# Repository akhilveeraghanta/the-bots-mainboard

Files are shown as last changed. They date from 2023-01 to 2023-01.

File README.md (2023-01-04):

# The Bots Mainboard

This is my first PCB design project. The majoriy of this board/schematics were created watching [Phils Lab](https://www.youtube.com/@PhilsLab) on youtube and using his projects as examples. 

The soccer playing AI will compute target velocities for all 6 robots and send them over USB to the mainboard, which will then send the velocity data over radio. Each robot will have its own mainboard, receive the pacet over radio, unpack and send a velocity command over the CAN Bus (which is then picked up by the motor controllers)

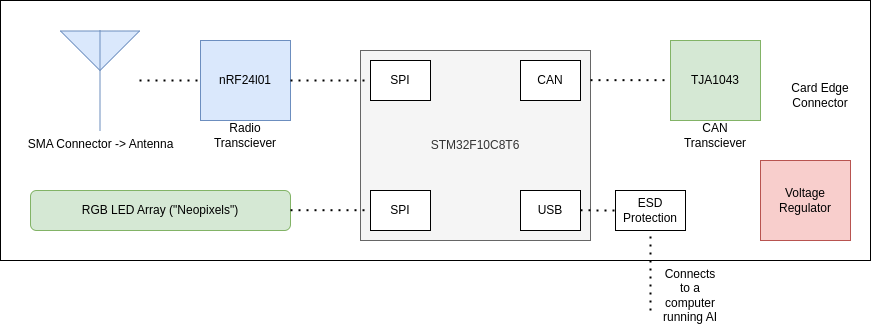
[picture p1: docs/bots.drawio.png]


So the main goal of the board is to act as a radio to CAN bridge if flashed as a robot, and a radio to USB bridge if flashed as a dongle and plugged into the computer running AI.

BoardyMcBoardFace

Additionally, the ball detector circuit, when plugged into a robot will be facing the "mouth" of the robot to detect any balls that enter. This helps with determining when to kick/chip the golf ball.

Here is one of our competitors, UBC Thunderbots's robot to put this board into perspective. (We don't have robots yet)



and more info about robocup can be [found here](https://ssl.robocup.org/)

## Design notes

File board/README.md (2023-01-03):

# the-bots-mainboard
The main board for the the bots SSL robocup team

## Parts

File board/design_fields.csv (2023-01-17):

Refs | Datasheet | Footprint | Value
C1 | ~ | Capacitor_SMD:C_0402_1005Metric | 10u
C10 | ~ | Capacitor_SMD:C_0402_1005Metric | 10n
C11 | ~ | Capacitor_SMD:C_0402_1005Metric | 10n
C12 | ~ | Capacitor_SMD:C_0402_1005Metric | 10n
C13 | ~ | Capacitor_SMD:C_0402_1005Metric | 0.1u
C14 | ~ | Capacitor_SMD:C_0402_1005Metric | 12p
C15 | ~ | Capacitor_SMD:C_0402_1005Metric | 12p
C16 | ~ | Capacitor_SMD:C_0402_1005Metric | 33n
C17 | ~ | Capacitor_SMD:C_0402_1005Metric | 10p
C18 | ~ | Capacitor_SMD:C_0402_1005Metric | 10p
C19 | ~ | Capacitor_SMD:C_0402_1005Metric | 1p5
C2 | ~ | Capacitor_SMD:C_0402_1005Metric | 100n
C20 | ~ | Capacitor_SMD:C_0402_1005Metric | 100n
C21 | ~ | Capacitor_SMD:C_0402_1005Metric | 1p
C22 | ~ | Capacitor_SMD:C_0402_1005Metric | 2n2
C23 | ~ | Capacitor_SMD:C_0402_1005Metric | 4p7
C25 | ~ | Capacitor_SMD:C_0402_1005Metric | 10n
C26 | ~ | Capacitor_SMD:C_0402_1005Metric | 22u
C27 | ~ | Capacitor_SMD:C_0805_2012Metric | 22u
C29 | ~ | Capacitor_SMD:C_0402_1005Metric | 10n
C3 | ~ | Capacitor_SMD:C_0402_1005Metric | 100n
C30 | ~ | Capacitor_SMD:C_0402_1005Metric | 0.1u
C32 | ~ | Capacitor_SMD:C_0402_1005Metric | 100n
C33 | ~ | Capacitor_SMD:C_0402_1005Metric | 100n
C34 | ~ | Capacitor_SMD:C_0402_1005Metric | 100n
C35 | ~ | Capacitor_SMD:C_0402_1005Metric | 100n
C36 | ~ | Capacitor_SMD:C_0402_1005Metric | 100n
C37 | ~ | Capacitor_SMD:C_0402_1005Metric | 100n
C38 | ~ | Capacitor_SMD:C_0402_1005Metric | 100n
C39 | ~ | Capacitor_SMD:C_0402_1005Metric | 100n
C4 | ~ | Capacitor_SMD:C_0402_1005Metric | 100n
C40 | ~ | Capacitor_SMD:C_0402_1005Metric | 100n
C41 | ~ | Capacitor_SMD:C_0402_1005Metric | 100n
C42 | ~ | Capacitor_SMD:C_0402_1005Metric | 100n
C43 | ~ | Capacitor_SMD:C_0402_1005Metric | 100n
C44 | ~ | Capacitor_SMD:C_0402_1005Metric | 100n
C45 | ~ | Capacitor_SMD:C_0402_1005Metric | 100n
C46 | ~ | Capacitor_SMD:C_0402_1005Metric | 100n
C5 | ~ | Capacitor_SMD:C_0402_1005Metric | 100n
C6 | ~ | Capacitor_SMD:C_0402_1005Metric | 100n
C7 | ~ | Capacitor_SMD:C_0402_1005Metric | 1u
C8 | ~ | Capacitor_SMD:C_0402_1005Metric | 1u
C9 | ~ | Capacitor_SMD:C_0402_1005Metric | 10u
D1 | https://cdn-shop.adafruit.com/datasheets/WS2812B.pdf | LED_SMD:LED_WS2812B-2020_PLCC4_2.0x2.0mm | WS2812B
D10 | ~ | LED_THT:LED_D5.0mm_IRGrey | D_Photo
D11 | https://cdn-shop.adafruit.com/datasheets/WS2812B.pdf | LED_SMD:LED_WS2812B-2020_PLCC4_2.0x2.0mm | WS2812B
D12 | https://cdn-shop.adafruit.com/datasheets/WS2812B.pdf | LED_SMD:LED_WS2812B-2020_PLCC4_2.0x2.0mm | WS2812B
D13 | https://cdn-shop.adafruit.com/datasheets/WS2812B.pdf | LED_SMD:LED_WS2812B-2020_PLCC4_2.0x2.0mm | WS2812B
D14 | https://cdn-shop.adafruit.com/datasheets/WS2812B.pdf | LED_SMD:LED_WS2812B-2020_PLCC4_2.0x2.0mm | WS2812B
D15 | https://cdn-shop.adafruit.com/datasheets/WS2812B.pdf | LED_SMD:LED_WS2812B-2020_PLCC4_2.0x2.0mm | WS2812B
D16 | https://cdn-shop.adafruit.com/datasheets/WS2812B.pdf | LED_SMD:LED_WS2812B-2020_PLCC4_2.0x2.0mm | WS2812B
D17 | https://cdn-shop.adafruit.com/datasheets/WS2812B.pdf | LED_SMD:LED_WS2812B-2020_PLCC4_2.0x2.0mm | WS2812B
D18 | https://cdn-shop.adafruit.com/datasheets/WS2812B.pdf | LED_SMD:LED_WS2812B-2020_PLCC4_2.0x2.0mm | WS2812B
D19 | https://cdn-shop.adafruit.com/datasheets/WS2812B.pdf | LED_SMD:LED_WS2812B-2020_PLCC4_2.0x2.0mm | WS2812B
D2 | ~ | LED_SMD:LED_0402_1005Metric | LED
D20 | https://cdn-shop.adafruit.com/datasheets/WS2812B.pdf | LED_SMD:LED_WS2812B-2020_PLCC4_2.0x2.0mm | WS2812B
D21 | https://cdn-shop.adafruit.com/datasheets/WS2812B.pdf | LED_SMD:LED_WS2812B-2020_PLCC4_2.0x2.0mm | WS2812B
D22 | ~ | LED_SMD:LED_0402_1005Metric | LED
D23 | https://cdn-shop.adafruit.com/datasheets/WS2812B.pdf | LED_SMD:LED_WS2812B-2020_PLCC4_2.0x2.0mm | WS2812B
D24 | https://cdn-shop.adafruit.com/datasheets/WS2812B.pdf | LED_SMD:LED_WS2812B-2020_PLCC4_2.0x2.0mm | WS2812B
D25 | https://cdn-shop.adafruit.com/datasheets/WS2812B.pdf | LED_SMD:LED_WS2812B-2020_PLCC4_2.0x2.0mm | WS2812B
D26 | https://cdn-shop.adafruit.com/datasheets/WS2812B.pdf | LED_SMD:LED_WS2812B-2020_PLCC4_2.0x2.0mm | WS2812B
D27 | ~ | LED_SMD:LED_0402_1005Metric | LED
D28 | ~ | LED_SMD:LED_0402_1005Metric | LED
D3 | http://www.alliedelec.com/m/d/40788c34903a719969df15f1fbea1056.pdf | LED_THT:LED_D5.0mm_IRGrey | LD271
D4 | ~ | LED_THT:LED_D5.0mm_IRGrey | D_Photo
D5 | ~ | Diode_SMD:D_0805_2012Metric | D_Schottky
D6 | ~ | Diode_SMD:D_0805_2012Metric | D_Schottky
D7 | https://cdn-shop.adafruit.com/datasheets/WS2812B.pdf | LED_SMD:LED_WS2812B-2020_PLCC4_2.0x2.0mm | WS2812B
D8 | ~ | LED_SMD:LED_0402_1005Metric | LED
D9 | http://www.alliedelec.com/m/d/40788c34903a719969df15f1fbea1056.pdf | LED_THT:LED_D5.0mm_IRGrey | LD271
FB1 | ~ | Inductor_SMD:L_0402_1005Metric | 120R
J1 | ~ | Connector_Coaxial:SMA_Samtec_SMA-J-P-X-ST-EM1_EdgeMount | SMA
J2 | ~ | Connector_PinHeader_1.27mm:PinHeader_2x05_P1.27mm_Vertical | ARM 10pin
J3 | ~ | Connector_USB:USB_Micro-B_Molex_47346-0001 | USB_B_Micro
J4 | ~ | Connector_PinHeader_1.27mm:PinHeader_1x02_P1.27mm_Vertical | Conn_01x02_Male
J5 | ~ | Connector_PinHeader_1.27mm:PinHeader_1x02_P1.27mm_Vertical | Conn_01x02_Male
J6 | ~ | Connector_PinHeader_1.27mm:PinHeader_1x02_P1.27mm_Vertical | Conn_01x02_Male
JP1 | ~ | Connector_PinHeader_1.27mm:PinHeader_1x02_P1.27mm_Vertical | Jumper_2_Open
JP2 | ~ | Connector_PinHeader_1.27mm:PinHeader_1x03_P1.27mm_Vertical | Jumper_3_Open
L1 | ~ | Inductor_SMD:L_0402_1005Metric | 3n9
L2 | ~ | Inductor_SMD:L_0402_1005Metric | 8n2
L3 | ~ | Inductor_SMD:L_0402_1005Metric | 2n7
R1 | ~ | Resistor_SMD:R_0402_1005Metric | 1M
R10 | ~ | Resistor_SMD:R_0402_1005Metric | 10k
R11 | ~ | Resistor_SMD:R_0402_1005Metric | 10k
R12 | ~ | Resistor_SMD:R_0402_1005Metric | 1k
R13 | ~ | Resistor_SMD:R_0402_1005Metric | 1k
R14 | ~ | Resistor_SMD:R_0402_1005Metric | 1k
R15 | ~ | Resistor_SMD:R_0402_1005Metric | 1k
R2 | ~ | Resistor_SMD:R_0402_1005Metric | 22k
R3 | ~ | Resistor_SMD:R_0402_1005Metric | 120
R4 | ~ | Resistor_SMD:R_0402_1005Metric | 100
R5 | ~ | Resistor_SMD:R_0402_1005Metric | 10k
R6 | ~ | Resistor_SMD:R_0402_1005Metric | 10k
R7 | ~ | Resistor_SMD:R_0402_1005Metric | 1k
R8 | ~ | Resistor_SMD:R_0402_1005Metric | 1k
R9 | ~ | Resistor_SMD:R_0402_1005Metric | 100
RV1 | ~ | Potentiometer_THT:Potentiometer_Bourns_3266X_Horizontal | R_POT 10k
RV2 | ~ | Potentiometer_THT:Potentiometer_Bourns_3266X_Horizontal | R_POT 10k
SW1 | ~ | Button_Switch_SMD:SW_Push_SPST_NO_Alps_SKRK | SW_Push
U$1 |  | ExtraStuff:M.2-B-KEY | M.2-B-KEY
U1 | http://www.nordicsemi.com/eng/content/download/2726/34069/file/nRF24L01P_Product_Specification_1_0.pdf | Package_DFN_QFN:QFN-20-1EP_4x4mm_P0.5mm_EP2.5x2.5mm | nRF24L01P
U2 | http://www.st.com/st-web-ui/static/active/en/resource/technical/document/datasheet/CD00161566.pdf | Package_QFP:LQFP-48_7x7mm_P0.5mm | STM32F103CBT6
U3 | http://www2.st.com/resource/en/datasheet/CD00050750.pdf | Package_TO_SOT_SMD:SOT-23-6 | USBLC6-2SC6
U4 | http://www.ti.com/lit/ds/symlink/lm393.pdf | Package_SO:SOIC-8_3.9x4.9mm_P1.27mm | LM393
U5 | http://www.advanced-monolithic.com/pdf/ds1117.pdf | Package_TO_SOT_SMD:SOT-223-3_TabPin2 | AMS1117-5.0
U6 | http://www.advanced-monolithic.com/pdf/ds1117.pdf | Package_TO_SOT_SMD:SOT-223-3_TabPin2 | AMS1117-3.3
U7 | http://www2.st.com/resource/en/datasheet/CD00050750.pdf | Package_TO_SOT_SMD:SOT-23-6 | USBLC6-2SC6
U8 | http://www2.st.com/resource/en/datasheet/CD00050750.pdf | Package_TO_SOT_SMD:SOT-23-6 | USBLC6-2SC6
U9 | http://www.nxp.com/documents/data_sheet/TJA1051.pdf | Package_SO:SOIC-8_3.9x4.9mm_P1.27mm | TJA1051T-3
Y1 | ~ | Crystal:Crystal_SMD_3225-4Pin_3.2x2.5mm | 16MHz
Y2 | ~ | Crystal:Crystal_SMD_3225-4Pin_3.2x2.5mm | 16MHz

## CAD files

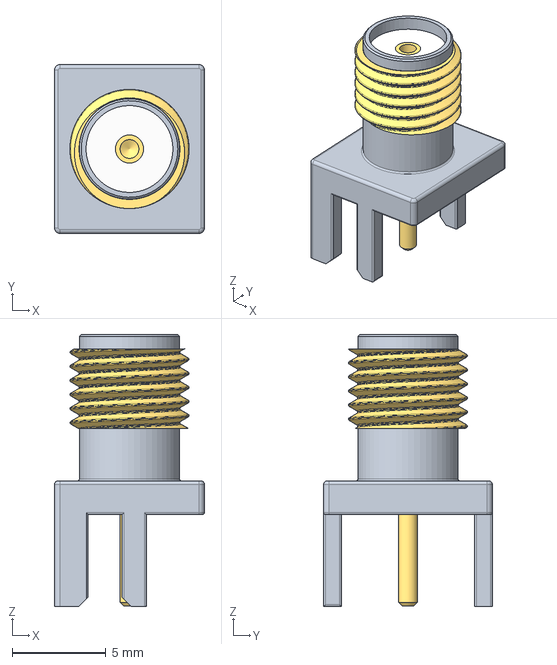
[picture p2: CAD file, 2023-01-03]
board/SMA-20.stp
8.00 x 9.00 x 14.5 mm

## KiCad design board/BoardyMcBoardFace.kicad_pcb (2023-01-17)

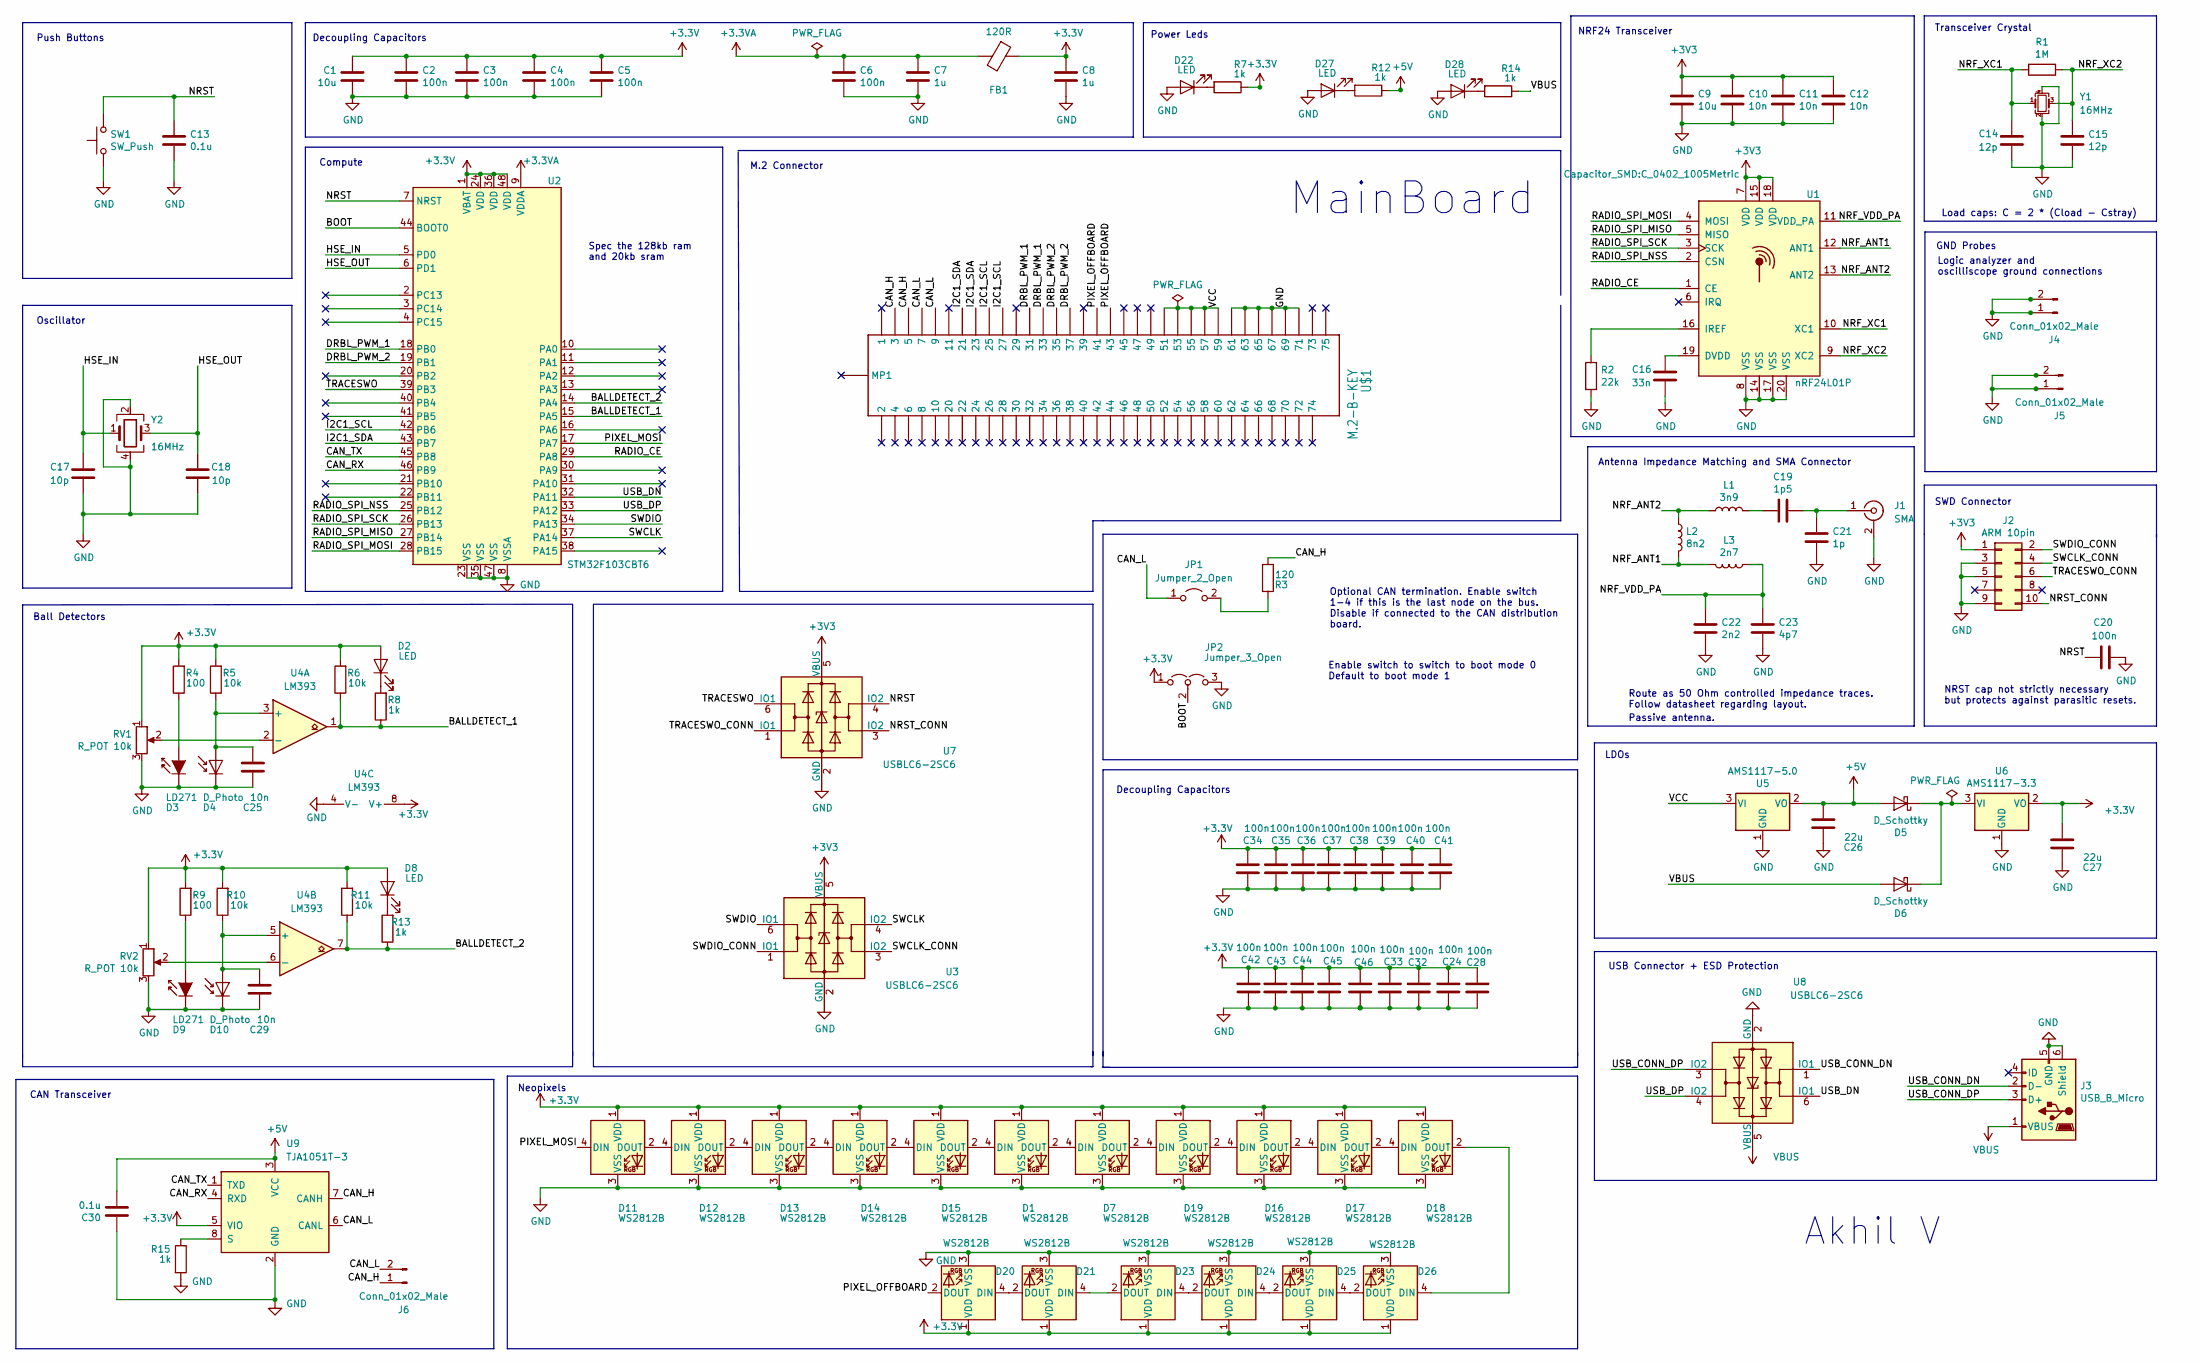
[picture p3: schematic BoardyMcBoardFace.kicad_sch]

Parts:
C1, C9: 10u; C_0402_1005Metric
C2, C3, C4, C5, C6, C20, C24, C28, C32, C33, C34, C35, C36, C37, C38, C39, C40, C41, C42, C43, C44, C45, C46: 100n; C_0402_1005Metric
C7, C8: 1u; C_0402_1005Metric
C10, C11, C12, C25, C29: 10n; C_0402_1005Metric
C13, C30: 0.1u; C_0402_1005Metric
C14, C15: 12p; C_0402_1005Metric
C16: 33n; C_0402_1005Metric
C17, C18: 10p; C_0402_1005Metric
C19: 1p5; C_0402_1005Metric
C21: 1p; C_0402_1005Metric
C22: 2n2; C_0402_1005Metric
C23: 4p7; C_0402_1005Metric
C26: 22u; C_0402_1005Metric
C27: 22u; C_0805_2012Metric
D1, D7, D11, D12, D13, D14, D15, D16, D17, D18, D19, D20, D21, D23, D24, D25, D26: WS2812B; LED_WS2812B-2020_PLCC4_2.0x2.0mm
D2, D8, D22, D27, D28: LED; LED_0402_1005Metric
D3, D9: LD271; LED_D5.0mm_IRGrey
D4, D10: D_Photo; LED_D5.0mm_IRGrey
D5, D6: D_Schottky; D_0805_2012Metric
FB1: 120R; L_0805_2012Metric
J1: SMA; SMA_Samtec_SMA-J-P-X-ST-EM1_EdgeMount
J2: ARM 10pin; PinHeader_2x05_P1.27mm_Vertical
J3: USB_B_Micro; USB_Micro-B_Molex_47346-0001
J4, J5, J6: Conn_01x02_Male; PinHeader_1x02_P1.27mm_Vertical
JP1: Jumper_2_Open; PinHeader_1x02_P1.27mm_Vertical
JP2: Jumper_3_Open; PinHeader_1x03_P1.27mm_Vertical
L1: 3n9; L_0402_1005Metric
L2: 8n2; L_0402_1005Metric
L3: 2n7; L_0402_1005Metric
R1: 1M; R_0402_1005Metric
R2: 22k; R_0402_1005Metric
R3: 120; R_0402_1005Metric
R4, R9: 100; R_0402_1005Metric
R5, R6, R10, R11: 10k; R_0402_1005Metric
R7, R8, R12, R13, R14, R15: 1k; R_0402_1005Metric
RV1, RV2: R_POT 10k; Potentiometer_Bourns_3266X_Horizontal
SW1: SW_Push; TS-1187A-B-A-B
U1: nRF24L01P; QFN-20-1EP_4x4mm_P0.5mm_EP2.5x2.5mm
U2: STM32F103CBT6; LQFP-48_7x7mm_P0.5mm
U3, U7, U8: USBLC6-2SC6; SOT-23-6
U4: LM393; SOIC-8_3.9x4.9mm_P1.27mm
U5: AMS1117-5.0; SOT-223-3_TabPin2
U6: AMS1117-3.3; SOT-223-3_TabPin2
U9: TJA1051T-3; SOIC-8_3.9x4.9mm_P1.27mm
U$1: M.2-B-KEY
Y1, Y2: 16MHz; Crystal_SMD_3225-4Pin_3.2x2.5mm

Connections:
+3.3VA: C6.1, C7.1, FB1.2, U2.9 (VDDA)
+5V: C26.2, C30.2, D5.2 (A), R12.1, U5.2 (VO), U9.3 (VCC)
/BALLDETECT_1: R6.1, R8.1, U2.15 (PA5), U4.1
/BALLDETECT_2: R11.1, R13.1, U2.14 (PA4), U4.7
/BOOT: JP2.2 (C), U2.44 (BOOT0)
/CAN_H: J6.1, R3.1, U9.7 (CANH), U$1.P$3 (3), U$1.P$5 (5)
/CAN_L: J6.2, JP1.1 (A), U9.6 (CANL), U$1.P$7 (7), U$1.P$9 (9)
/CAN_RX: U2.46 (PB9), U9.4 (RXD)
/CAN_TX: U2.45 (PB8), U9.1 (TXD)
/DRBL_PWM_1: U2.18 (PB0), U$1.P$31 (31), U$1.P$33 (33)
/DRBL_PWM_2: U2.19 (PB1), U$1.P$35 (35), U$1.P$37 (37)
/HSE_IN: C17.1, U2.5 (PD0), Y2.1
/HSE_OUT: C18.1, U2.6 (PD1), Y2.3
/I2C1_SCL: U2.42 (PB6), U$1.P$25 (25), U$1.P$27 (27)
/I2C1_SDA: U2.43 (PB7), U$1.P$21 (21), U$1.P$23 (23)
/NRF_ANT1: L2.2, L3.2, U1.12 (ANT1)
/NRF_ANT2: L1.1, L2.1, U1.13 (ANT2)
/NRF_VDD_PA: C22.2, C23.2, L3.1, U1.11 (VDD_PA)
/NRF_XC1: C14.1, R1.2, U1.10 (XC1), Y1.1
/NRF_XC2: C15.1, R1.1, U1.9 (XC2), Y1.3
/NRST: C13.1, C20.1, SW1.2, U2.7 (NRST), U7.4 (IO2)
/NRST_CONN: J2.10, U7.3 (IO2)
/PIXEL_MOSI: D11.4 (DIN), U2.17 (PA7)
/PIXEL_OFFBOARD: D20.2 (DOUT), U$1.P$41 (41), U$1.P$43 (43)
/RADIO_CE: U1.1 (CE), U2.29 (PA8)
/RADIO_SPI_MISO: U1.5 (MISO), U2.27 (PB14)
/RADIO_SPI_MOSI: U1.4 (MOSI), U2.28 (PB15)
/RADIO_SPI_NSS: U1.2 (CSN), U2.25 (PB12)
/RADIO_SPI_SCK: U1.3 (SCK), U2.26 (PB13)
/SWCLK: U2.37 (PA14), U3.4 (IO2)
/SWCLK_CONN: J2.4, U3.3 (IO2)
/SWDIO: U2.34 (PA13), U3.6 (IO1)
/SWDIO_CONN: J2.2, U3.1 (IO1)
/TRACESWO: U2.39 (PB3), U7.6 (IO1)
/TRACESWO_CONN: J2.6, U7.1 (IO1)
/USB_CONN_DN: J3.2 (D-), U8.1 (IO1)
/USB_CONN_DP: J3.3 (D+), U8.3 (IO2)
/USB_DN: U2.32 (PA11), U8.6 (IO1)
/USB_DP: U2.33 (PA12), U8.4 (IO2)
/VCC: U5.3 (VI), U$1.P$51 (51), U$1.P$53 (53), U$1.P$55 (55), U$1.P$57 (57), U$1.P$59 (59)
GND: C1.2, C2.2, C3.2, C4.2, C5.2, C6.2, C7.2, C8.2, C9.2, C10.2, C11.2, C12.2, C13.2, C14.2, C15.2, C16.2, C17.2, C18.2, C20.2, C21.1, C22.1, C23.1, C24.2, C25.2, C26.1, C27.1, C28.2, C29.2, C30.1, C32.2, C33.2, C34.2, C35.2, C36.2, C37.2, C38.2, C39.2, C40.2, C41.2, C42.2, C43.2, C44.2, C45.2, C46.2, D1.3 (VSS), D3.1 (K), D4.1 (K), D7.3 (VSS), D9.1 (K), D10.1 (K), D11.3 (VSS), D12.3 (VSS), D13.3 (VSS), D14.3 (VSS), D15.3 (VSS), D16.3 (VSS), D17.3 (VSS), D18.3 (VSS), D19.3 (VSS), D20.3 (VSS), D21.3 (VSS), D22.2 (A), D23.3 (VSS), D24.3 (VSS), D25.3 (VSS), D26.3 (VSS), D27.2 (A), D28.2 (A), J1.2 (Ext), J2.3, J2.5, J2.9, J3.5 (GND), J3.6 (Shield), J4.1, J4.2, J5.1, J5.2, JP2.3 (B), R2.2, R15.2, RV1.3, RV2.3, SW1.1, U1.8 (VSS), U1.14 (VSS), U1.17 (VSS), U1.20 (VSS), U2.8 (VSSA), U2.23 (VSS), U2.35 (VSS), U2.47 (VSS), U3.2 (GND), U4.4 (V-), U5.1 (GND), U6.1 (GND), U7.2 (GND), U8.2 (GND), U9.2 (GND), U$1.P$61 (61), U$1.P$63 (63), U$1.P$65 (65), U$1.P$67 (67), U$1.P$69 (69), U$1.P$71 (71), Y1.2, Y1.4, Y2.2, Y2.4
unnamed: C16.1, U1.19 (DVDD)
unnamed: C19.1, C21.2, J1.1 (In)
unnamed: C19.2, L1.2
unnamed: C25.1, D4.2 (A), R5.1, U4.3 (+)
unnamed: C29.1, D10.2 (A), R10.1, U4.5 (+)
unnamed: D1.2 (DOUT), D7.4 (DIN)
unnamed: D1.4 (DIN), D15.2 (DOUT)
unnamed: D2.1 (K), R8.2
unnamed: D3.2 (A), R4.1
unnamed: D5.1 (K), D6.1 (K), U6.3 (VI)
unnamed: D8.1 (K), R13.2
unnamed: D9.2 (A), R9.1
unnamed: D11.2 (DOUT), D12.4 (DIN)
unnamed: D12.2 (DOUT), D13.4 (DIN)
unnamed: D13.2 (DOUT), D14.4 (DIN)
unnamed: D14.2 (DOUT), D15.4 (DIN)
unnamed: D16.2 (DOUT), D17.4 (DIN)
unnamed: D16.4 (DIN), D19.2 (DOUT)
unnamed: D17.2 (DOUT), D18.4 (DIN)
unnamed: D18.2 (DOUT), D26.4 (DIN)
unnamed: D7.2 (DOUT), D19.4 (DIN)
unnamed: D20.4 (DIN), D21.2 (DOUT)
unnamed: D21.4 (DIN), D23.2 (DOUT)
unnamed: D22.1 (K), R7.2
unnamed: D23.4 (DIN), D24.2 (DOUT)
unnamed: D24.4 (DIN), D25.2 (DOUT)
unnamed: D25.4 (DIN), D26.2 (DOUT)
unnamed: D27.1 (K), R12.2
unnamed: D28.1 (K), R14.2
unnamed: JP1.2 (B), R3.2
unnamed: R2.1, U1.16 (IREF)
unnamed: R15.1, U9.8 (S)
unnamed: RV1.2, U4.2 (-)
unnamed: RV2.2, U4.6 (-)
VBUS: D6.2 (A), J3.1 (VBUS), R14.1, U8.5 (VBUS)

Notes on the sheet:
Load caps: C = 2 * (Cload - Cstray)
USB Connector + ESD Protection
Logic analyzer and oscilliscope ground connections
Spec the 128kb ram and 20kb sram
Push Buttons
NRST cap not strictly necessary but protects against parasitic resets.
Route as 50 Ohm controlled impedance traces. Follow datasheet regarding layout.
LDOs
Transceiver Crystal
Decoupling Capacitors
MainBoard
Antenna Impedance Matching and SMA Connector
Optional CAN termination. Enable switch 1-4 if this is the last node on the bus. Disable if connected to the CAN distribution board.
M.2 Connector
GND Probes
CAN Transceiver
Enable switch to switch to boot mode 0 Default to boot mode 1
Power Leds
Neopixels
Akhil V
Oscillator
Ball Detectors
Decoupling Capacitors
NRF24 Transceiver
Compute
SWD Connector
Passive antenna.

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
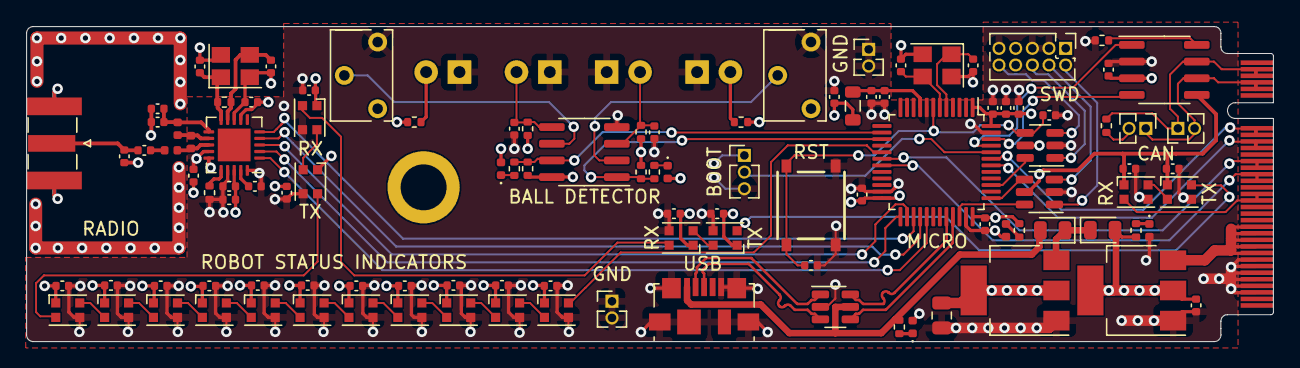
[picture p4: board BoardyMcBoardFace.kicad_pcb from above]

Board: 4 copper layers, 95.0 x 24.0 mm, 115 parts (0 on the bottom side), 77 nets.

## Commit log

2023-01-03 move from private repo
    [BoardyMcBoardFace.kicad_pcb, BoardyMcBoardFace.kicad_sch, BoardyMcBoardFace.sch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]
2023-01-03 move files
    [BoardyMcBoardFace.kicad_pcb, BoardyMcBoardFace.kicad_sch, BoardyMcBoardFace.sch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]
2023-01-04 move stuff aroud
    [BoardyMcBoardFace.kicad_pcb, BoardyMcBoardFace.kicad_sch]
2023-01-05 final touches
    [BoardyMcBoardFace.kicad_pcb, BoardyMcBoardFace.kicad_sch]
